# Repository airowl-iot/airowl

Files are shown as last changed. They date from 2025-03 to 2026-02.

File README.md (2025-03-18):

<div align="center">

# **AIROWL**

The Airowl is an indoor Air Quality Measurement device comprising of the ESP32 S3 powered M5stack Core S3 SE, which integrates the aforementioned controller chip, with a 320 x 240 LCD screen supporting capacitive touch, along with a speaker and the AXP2101 power management chip.



</div>

# Airowl is Now Matter-Compatible

Airowl now supports [**Matter**](https://en.wikipedia.org/wiki/Matter_(standard)), the new smart home standard, enabling seamless integration with **Apple HomeKit, Google Home**, and other Matter-supported ecosystems. Check the [Firmware](./Firmware) for details on Matter integration.

This repository serves as the source of the complete Airowl, consisting of its firmware source files, 3D files, and PCB design files.

This file provides instructions to assemble the individual components of the Airowl, along with its Bill of Materials (BOM).

## The BOM for the Airowl is as Follows:

| SR. | ITEM DESCRIPTION | NOTES | Qty | Product Links |
|-----|---|---|-----|---|
| 1 | M5 STACK | SCREEN | 1 | <a href="https://shop.m5stack.com/products/m5stack-cores3-se-iot-controller-w-o-battery-bottom" target="_blank">Link</a> |
| 2 | FRONT FACIA | UV FRONT 1.3 MM + REAR BLACK 5 MM | 1 | [Front](/Designfiles/Frontfacia) |
| 3 | 3D PRINT BACK CASE | BLACK MATTLE 3D PRINTED CASE | 1 | [Back](/Designfiles/Backcover) |
| 4 | FASTENERS | M3 X 8 mm PHILIPS HEAD (SS) | 2 | |
| 5 | FASTENERS | M3 X 20 mm CSK Blunted (SS) | 2 | |
| 6 | FASTENERS | M3 X 25 mm CSK Blunted (SS) | 2 | |
| 7 | Screw Driver (+) | Mini Screw Driver | 1 | |
| 8 | TYPE C - TYPE C CABLE | PORTRONICS TYPE C CABLE | 1 | |

More details of the individual components can be found as followed:

[PCB files](/Mountingboard/)

[Firmware](/Firmware)

[Squareline studio project files](/squareline/) 

[Design Files](/Designfiles/)

## Assembling the Airowl

The following is a cross sectional view of the Airowl dpicting its individual components and the way that they must be connected:

Design Files

From left to right, we can observe the parts as follows:

1. Screws
2. [3D printed Black Case](Images/16.png)
3. [Printed circuit Board](Images/19.png)
4. M5 stack Core S3 SE
5. Sensirion SEN 54 sensor
6. [Front Cover](Images/15.png)

Ensure that the screws are connected correctly as depicted in the above picture, incase the screws are connected incorrectly, the longer screws might damage the physical cover of the Airowl.

On assembling the Airowl, it appears like depicted below:



On following the instructions in [Firmware](/Firmware/), the Airowl can be programmed succesfully.

Check this repository releases for newer firmware updates.

## Made by the Community, with -❤️-:

<a href="https://github.com/oizom-iot/airowl/graphs/contributors">
  
</a>

## Licensing

Airowl is available under MIT License

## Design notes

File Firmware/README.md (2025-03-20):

# Firmware

This folder contains the firmware files used to program the Airowl. The Folder consists of various folders used by PlatformIO to configure and program the project.

## Using PlatformIO
PlatformIO is a VS code extension that enables us to program microcontrollers using VS code. The PlatformIO core supports more than 1500 development boards including the M5 core S3 used in the Airowl. PlatformIO supports both esp-idf and arduino environments. 

### Step 1  Installing PlatformIO 
PlatformIO can be installed using the extensions feature in Visual Studio Code.

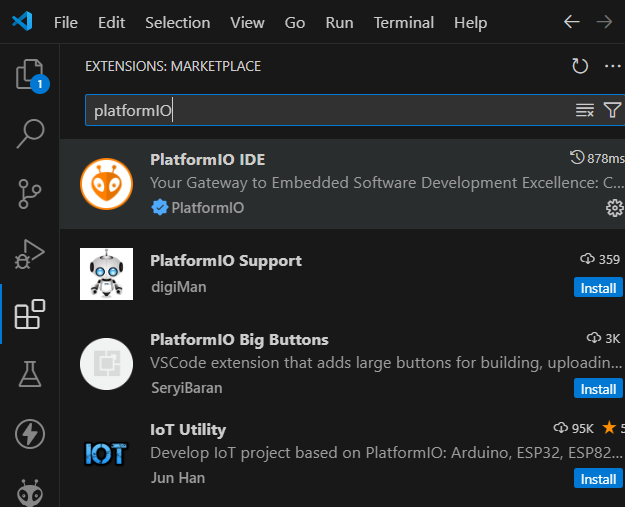
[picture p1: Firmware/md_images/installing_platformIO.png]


### Step 2 Using PlatformIO with Airowl Firmware

In order to program the Airowl with the firmware, download and extract this repository or clone it.
Open platformIO using the platformIO icon from the sidebar.

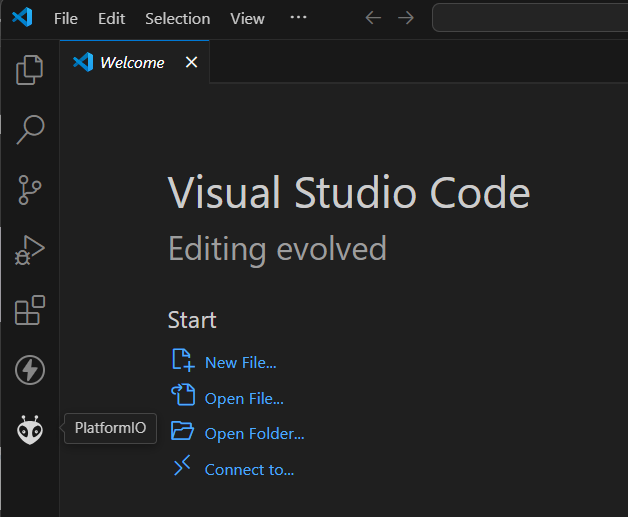
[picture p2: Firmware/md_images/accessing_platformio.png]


Open PIO home to access platformIO, this opens a new tab in VS code which can be used to create/open projects.

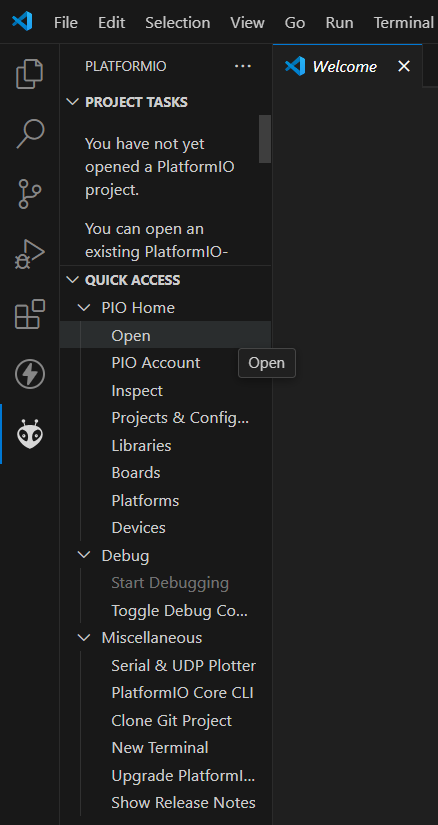
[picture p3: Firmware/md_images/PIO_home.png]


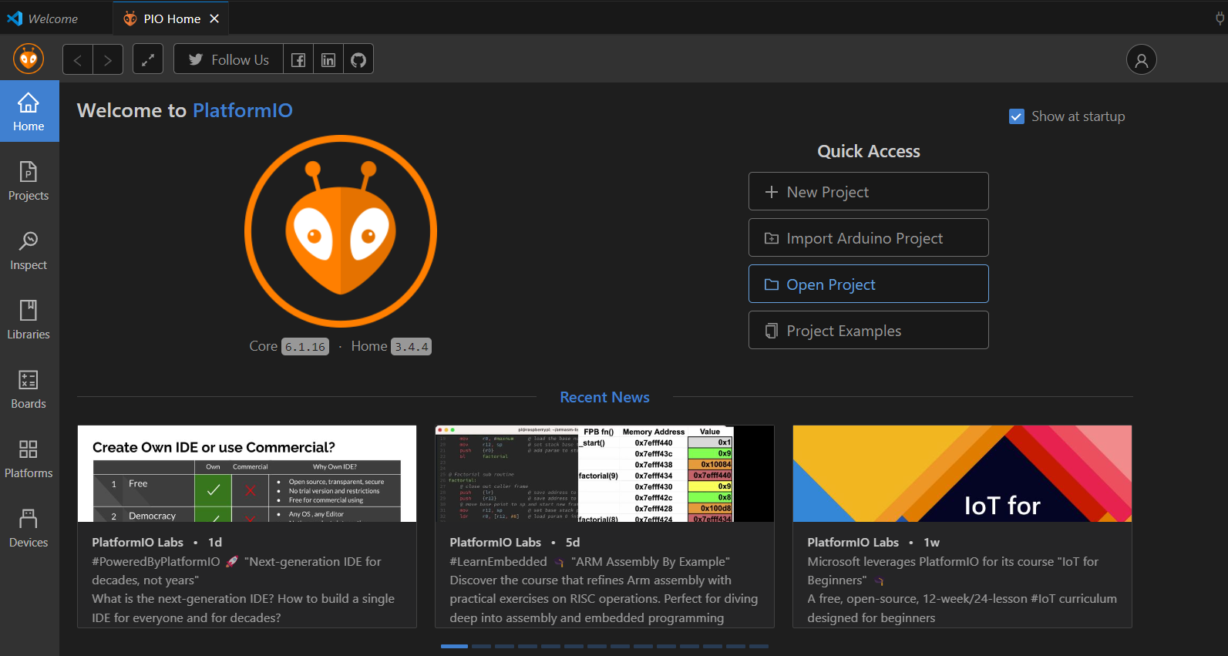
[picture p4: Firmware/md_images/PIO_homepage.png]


Click on Open Project button as highlighted in the above picture and locate the downloaded repository, and open the Firmware folder. Ensure that the folder has platformio.ini file present in it as this file acts as the config file for platformio and is essential to program the firmware to the Airowl. 

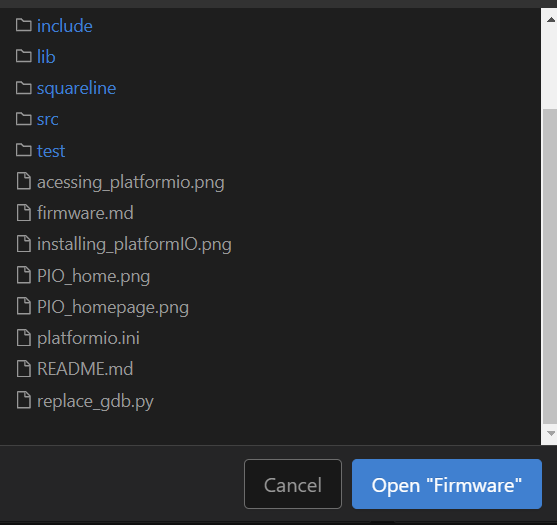
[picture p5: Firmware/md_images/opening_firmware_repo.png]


### Step 3  Uploading to the device using PlatformIO

Once the platformio.ini file is loaded, ensure that Airowl is connected to your PC, and upload the firmware using the PlatformIO : upload button



The terminal displays the upload status and on Successful upload displays the following :

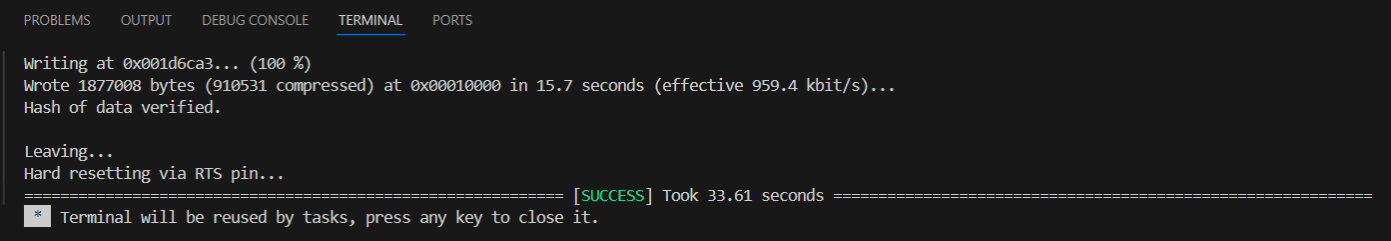
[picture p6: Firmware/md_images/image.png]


# Airowl Matter Device - Smart Home Integration

Airowl is a **Matter-compatible** device designed for seamless integration into various smart home ecosystems, including **Apple Home, Google Home, Amazon Alexa, Samsung SmartThings, Home Assistant and Other Supported Matter Ecosystem**. Unlike other devices that require a physical pairing button, Airowl **automatically enters pairing mode** after connecting to Wi-Fi using Wi-Fi Manager.

---

## 🔗 Supported Smart Home Ecosystems

Airowl can be added to the following **Matter-compatible** smart home platforms:

- **Apple Home**  
- **Google Home**  
- **Amazon Alexa**  
- **Samsung SmartThings**  
- **Home Assistant**
- **Other Supported Matter Ecosystem**
---

## 📲 Pairing Airowl with Apple Home

### Step 1: Power on the Airowl Device
- Connect the device to a **power source**.
- The device will create a **Wi-Fi hotspot** (e.g., **"Airowl-Setup"**).

### Step 2: Connect to Airowl’s Wi-Fi and Configure  
1. **Open Wi-Fi settings** on your phone and connect to **Airowl’s Wi-Fi** (SSID shown on the device).  
2. Once connected, a **Wi-Fi Manager portal** will open automatically. If not, go to **`192.168.4.1`** in a browser.  
3. Select your **home Wi-Fi network** and enter the password.  
4. Tap **Connect**, and Airowl will join your network.  

🚀 **At this point, the device automatically enters pairing mode!**  

### Step 3: Open Apple Home App  
1. Open the **Apple Home** app on your iPhone.  
2. Tap the **“+” (Add Accessory)** button in the top-right corner.  
3. Select **“Add Accessory.”**  

### Step 4: Scan the Matter QR Code

- Locate the **Matter QR Code** (on the device or in the documentation).
- Use your **iPhone camera** to scan the QR code.
- If there's no QR code, tap **“More Options”** and select the device from the list.

#### Matter QR Code:
Matter QR Code

#### Manual Pairing Code:
`34970112332`

### Step 5: Complete Setup  
- **Apple Home** will detect the Airowl device and guide you through the pairing process.  
- Assign it a **room** and a **custom name** (e.g., **"Living Room Air Sensor"**).  
- The device will now appear in **Apple Home**.  

---

## Squareline Studio

[Squareline Studio](https://squareline.io/) is a software that enables us to develop User Interface using LVGL, such that the tool converts visual design into LVGL based code allowing us to integrate images, logos, etc. in the project. 

[Squareline Studio Documentation](https://docs.squareline.io/docs/squareline/) 

Inside the firmware folder, the directory named [Squareline](/squareline/) stores the project files from squareline studio, these files contain the UI design.

### Step 1. Opening the Squareline Studio Project Files

[example_project.spj](/squareline/projects/ui_square_line/example_project.spj) is the squareline studio project file.

On launching Squareline Studio, click on the Import project button using which [example_project.spj](/squareline/projects/ui_square_line/example_project.spj) can be located and opened and modified accordingly.

On opening the project, we can see the various UI elements used to create the UI - such as the screens, images, buttons and the graphs created to portray the changing values of the parameters - measured using the SEN 54 sensor. 
Custom animations have been made for the Airowl with events created to trigger them.

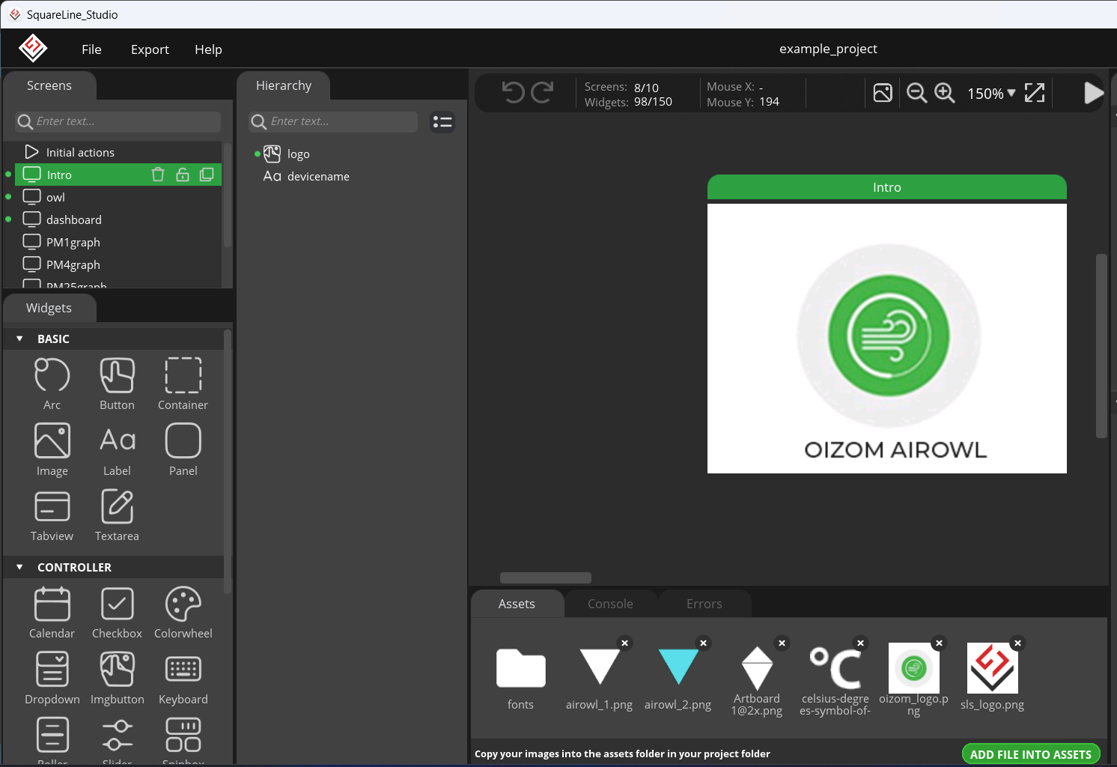
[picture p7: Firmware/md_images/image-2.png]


The screens panel on the side is jused to handle the screens, whereas  Widgets tab is used to add buttons/ containers/ labels etc.

The assets tab below the screens view is used to add images/ fonts to be used in the design.
Using the Add File into ASSETS option, more images can be added into the project.

On selecting the appropriate screen , the elements inside it are visible in the Heirarchy tab.

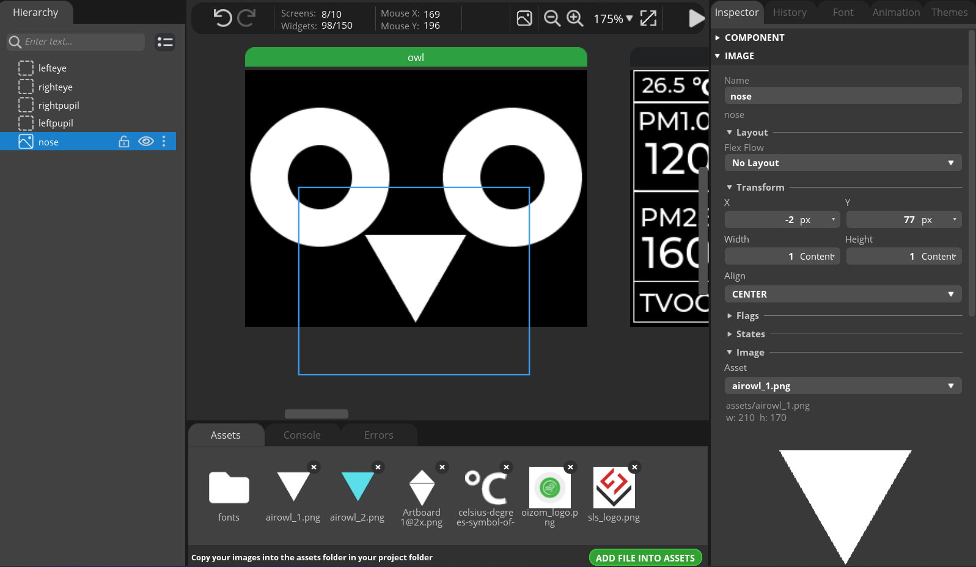
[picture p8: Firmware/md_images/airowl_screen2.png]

On selecting the element, we can modify the properties of the element through the inspector tab on the right such as size, position.
The font tab is used to handle the fonts used in the project.

The animation tab is usd to create/modify animations, the animations can be lated applied to different targets in the inspector tab.
The animations can be binded to events based on screen touch/ timeout basis from the inspector tab.

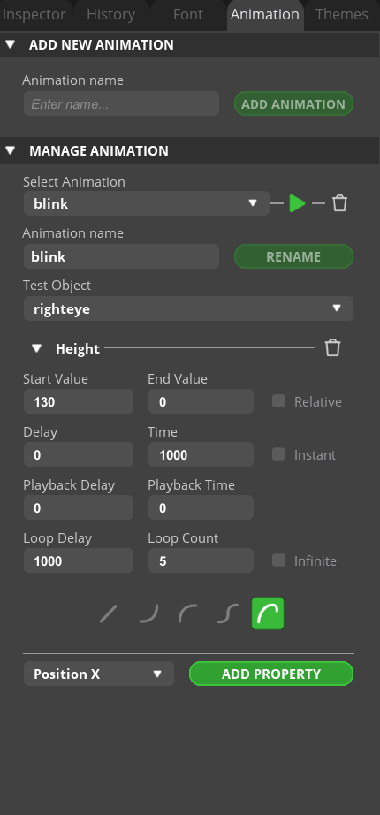
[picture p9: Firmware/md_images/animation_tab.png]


The white play button on the top (left of Inspector tab) can be clicked to simulate the animation, before using it in the Firmware.

### Step 2. Exporting the UI Files
Once the UI has been created , it is time to export the UI files. This can be done using the Export option on the top-left of the window. However, we must first ensure that the UI export path is correctly set inside the correct directory, this can be done using the file -> project settings option as depicted below:

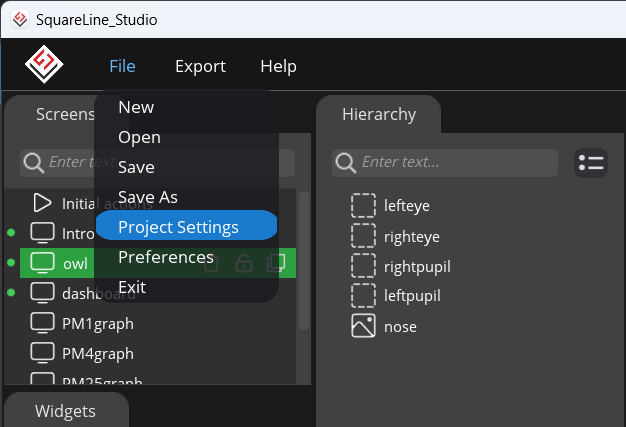
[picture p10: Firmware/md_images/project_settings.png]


It must be ensured that the Project export path is [ui_square_line](/squareline/projects/ui_square_line/) and the UI files export path is set to [/src/m5stack/ui/](/src/m5stack/ui/), this ensures that on updating the UI and exporting the UI files through Squareline Studio, the changes are reflected in the Firmware.

## src/m5stack

This folder contains the main files of the firmware. The C files, header files , UI files are all located inside this directory.

### ui
This folder contains the exported UI files from squareline studio (in source code format)

The fonts folder contains the custom fonts that we had added in the assets folder in squareline studio, the images folder contains the images used for the UI in C code, while the screens folder contains the C files for the various screens used in the UI design.
These files declare and use different objects to display the elements on the 320 x 240 LCD screen of the Airowl. Referencing these objects, and their types, we can manipulate them accordingly in order to update the UI based on sensor data and touch events.

The ui.c and ui.h files define all the animation functions, the labels, the conatiners and the objects that are used in the UI.These files also bind these objects to their repective LVGL components.

### main.cpp

Similar to Arduino IDE's .ino files, the main.cpp file consists of the setup() and loop() functions, this is actually the file executed by the platformIO core. It consists of inclusion of other header and UI files, which facilitates the usage of UI, and allows the functioning of I2C,Wifi,RTOS, MQTT functionality.
### Sensor.h 

The Sensor.h file acts as the backbone of the firmware. It defines and calls most functions required by the firmware.

To handle the SEN54 sensor, the file utilizes the appropriate library - <SensirionI2CSen5x.h>, this is the original arduino platform library, and handles the SEN 54 .

The Wire.h is the standard library used to handle I2C communication between the M5 Core S3's ESP32S3 microcontroller and the sensor. The M5 coreS3 and SEN 54 have interfaced as follows: 

1. SEN 54 VDD -> 5V 

2. SEN 54 GND -> GND

3. SEN 54 SCL -> G1

4. SEN 54 SDA -> G2

5. SEN 54 SEL -> GND    

Refer to the Pinmap of M5 core S3 SE below:

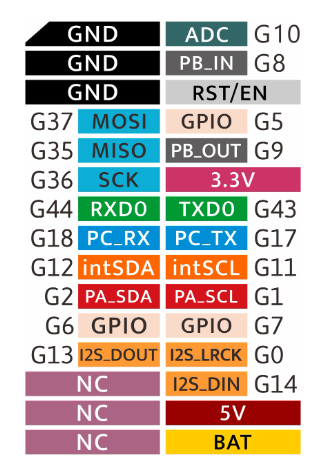
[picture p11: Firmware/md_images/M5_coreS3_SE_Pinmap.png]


Various LVGL UI objects are used in this file to overwrite/update the values displayed on the screen.
A data frequency of 150 has been defined which ensures that the graphs depicting PM1.0, PM 2.5, PM 4.0, PM 10.0 and TVOC are updated every 5 mins.

The live data is displayed on the dashboard screen, where the screen is divided into buttons, on touching the corresponding button, the graph of its parameter is displayed.

Functions - getAQIBreakpoint and getAQIColor are used to quantify the air quality index based on the PM and TVOC values, based on the AQI, the colors on the dashboard and the Owl screen are also updated.

Moreover Wifi.h and PubSubClient.h files are included to facilitate Wifi and MQTT functionalities respectively.

### time_func.h

This File handles the syncronization of the time label on the dashboard screen with the NTP server, using WifiManager functions.

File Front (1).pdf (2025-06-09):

## Step 3: Install the M5 Stack

## Congratulations !

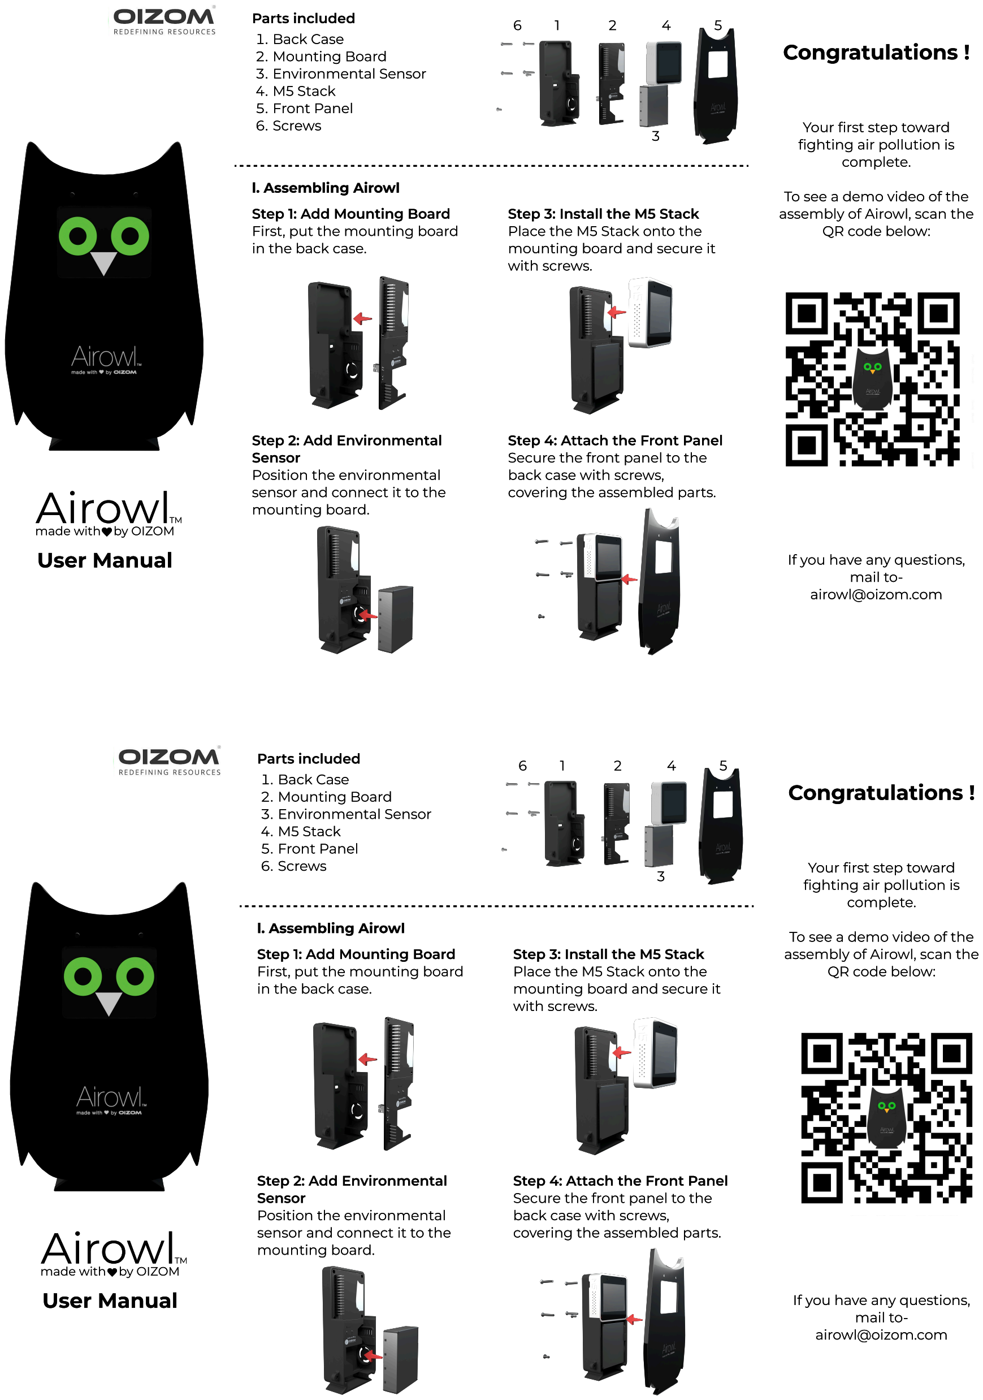
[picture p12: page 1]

## User Manual

### made with by OIZOM AirowlTM

Step 1: Add Mounting Board

First, put the mounting board

in the back case.

Place the M5 Stack onto the

mounting board and secure it

with screws.

Step 2: Add Environmental

Sensor

Position the environmental

sensor and connect it to the

mounting board.

### Step 4: Attach the Front Panel

Secure the front panel to the

back case with screws,

covering the assembled parts.

l. Assembling Airowl

Your first step toward

fighting air pollution is

complete.

To see a demo video of the

assembly of Airowl, scan the

QR code below:

If you have any questions,

## mail to-airowl@oizom.com

## Parts included

## +D Back Cas9

4D Mounting Boar(

/D Environmental Senso)

## AD M5 Stac2

:D Front Pane#

D Screws

6 | 1 | 2 | 4 | 5

3

## Parts included

## +D Back Cas9

4D Mounting Boar(

/D Environmental Senso)

## AD M5 Stac2

:D Front Pane#

D Screws

6 | 1 | 2 | 4 | 5

## Congratulations !

Your first step toward

fighting air pollution is

complete.

To see a demo video of the

assembly of Airowl, scan the

QR code below:

3

l. Assembling Airowl
Step 1: Add Mounting Board

First, put the mounting board

in the back case.

## Step 3: Install the M5 Stack

Place the M5 Stack onto the

mounting board and secure it

with screws.

Step 2: Add Environmental

Sensor

Position the environmental

sensor and connect it to the

mounting board.

### Step 4: Attach the Front Panel

Secure the front panel to the

back case with screws,

covering the assembled parts.

## User Manual

### made with by OIZOM AirowlTM

If you have any questions,

## mail to-airowl@oizom.com

## Parts included

## +D Back Cas9

4D Mounting Boar(

/D Environmental Senso)

## AD M5 Stac2

:D Front Pane#

D Screws

6 | 1 | 2 | 4 | 5

## Congratulations !

Your first step toward

fighting air pollution is

complete.

To see a demo video of the

assembly of Airowl, scan the

QR code below:

3

l. Assembling Airowl
Step 1: Add Mounting Board

First, put the mounting board

in the back case.

## Step 3: Install the M5 Stack

Place the M5 Stack onto the

mounting board and secure it

with screws.

Step 2: Add Environmental

Sensor

Position the environmental

sensor and connect it to the

mounting board.

### Step 4: Attach the Front Panel

Secure the front panel to the

back case with screws,

covering the assembled parts.

## User Manual

### made with by OIZOM AirowlTM

If you have any questions,

## mail to-airowl@oizom.com

## Parts included

## +D Back Cas9

4D Mounting Boar(

/D Environmental Senso)

## AD M5 Stac2

:D Front Pane#

D Screws

6 | 1 | 2 | 4 | 5

## Congratulations !

Your first step toward

fighting air pollution is

complete.

To see a demo video of the

assembly of Airowl, scan the

QR code below:

3

l. Assembling Airowl
Step 1: Add Mounting Board

First, put the mounting board

in the back case.

## Step 3: Install the M5 Stack

Place the M5 Stack onto the

mounting board and secure it

with screws.

Step 2: Add Environmental

Sensor

Position the environmental

sensor and connect it to the

mounting board.

### Step 4: Attach the Front Panel

Secure the front panel to the

back case with screws,

covering the assembled parts.

## User Manual

### made with by OIZOM AirowlTM

If you have any questions,

## mail to-airowl@oizom.com

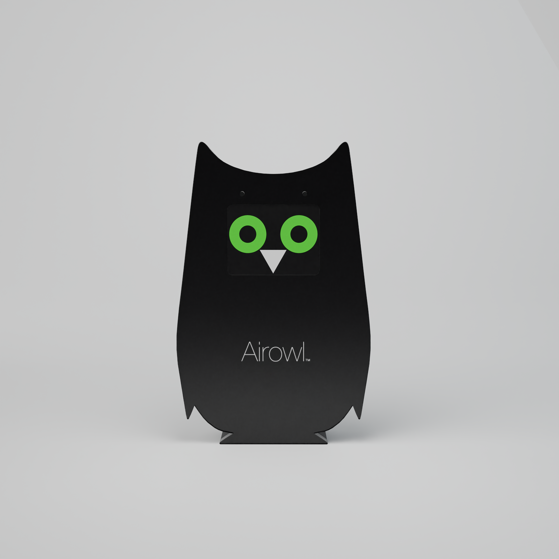
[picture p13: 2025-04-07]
Images/AIROWL edited renders and animation/n 2.png

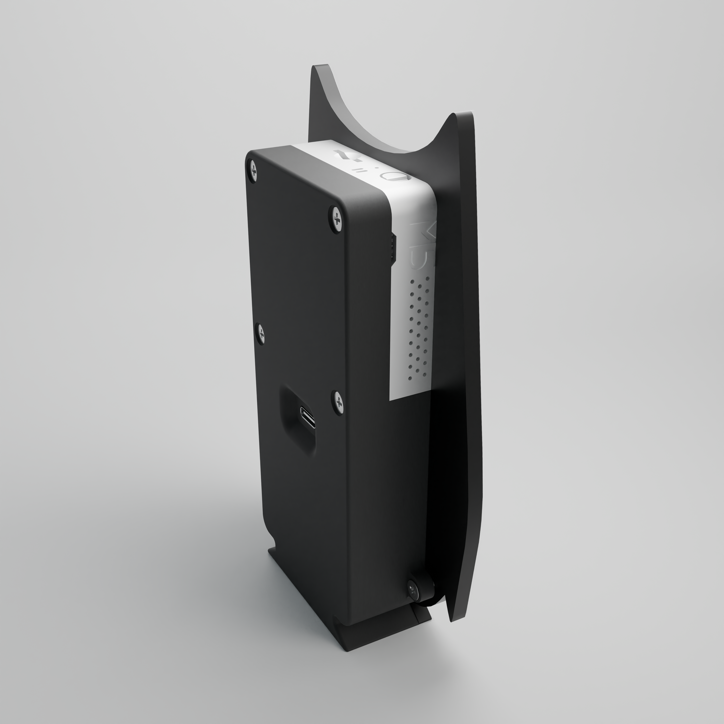
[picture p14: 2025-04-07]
Images/AIROWL edited renders and animation/n 3.png

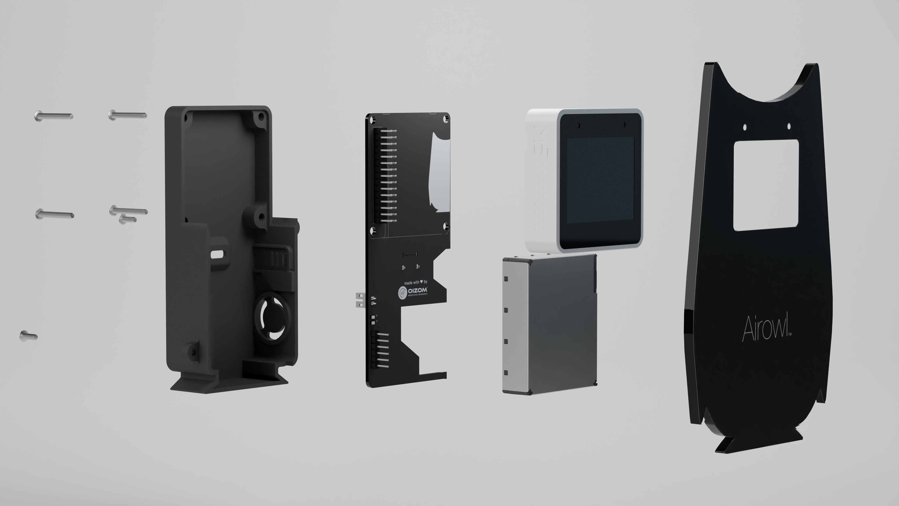
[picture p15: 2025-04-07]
Images/AIROWL edited renders and animation/n 6.png

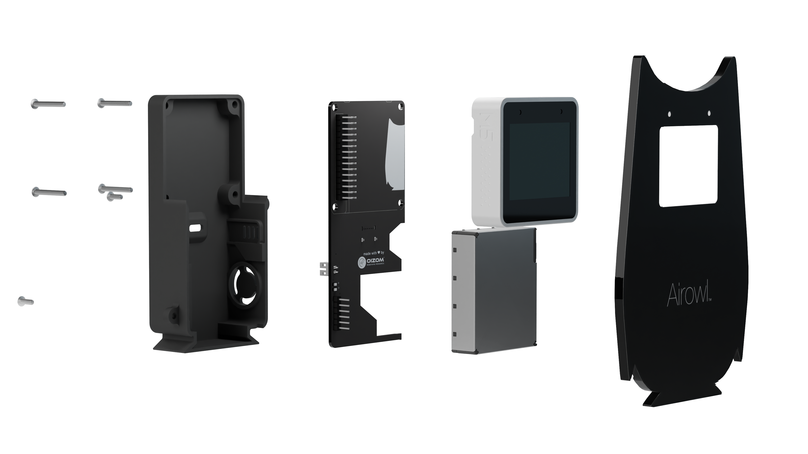
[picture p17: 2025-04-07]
Images/AIROWL edited renders and animation/n 6e.png

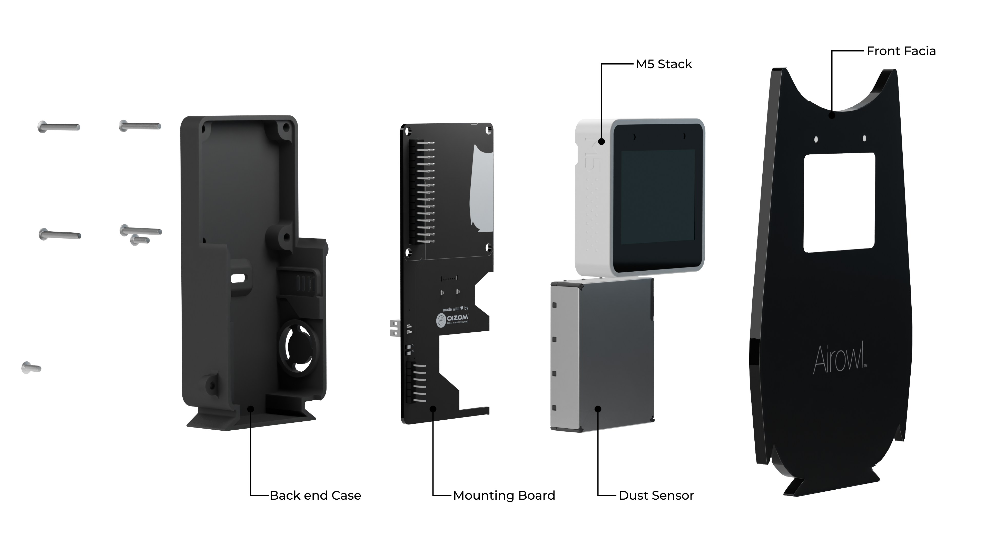
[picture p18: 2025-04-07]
Images/AIROWL edited renders and animation/n 6e2.png

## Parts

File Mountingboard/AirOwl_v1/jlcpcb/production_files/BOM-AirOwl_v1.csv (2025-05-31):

Comment | Designator | Footprint | LCSC
10K | R2 | R_0805_2012Metric_Pad1.20x1.40mm_HandSolder
10K | R1 | R_0805_2012Metric_Pad1.20x1.40mm_HandSolder
Conn_01x06 | J2 | PinHeader_1x06_P2.54mm_Vertical
USB_C_Receptacle_PowerOnly_6P | J4 | MOLEX_2171780001
SS34 | D2 | D_SMA
CoreSE | U1 | CoreS3
Conn_01x02 | J3 | JST_PH_B2B-PH-K_1x02_P2.00mm_Vertical
10K | R4 | R_0805_2012Metric_Pad1.20x1.40mm_HandSolder
10K | R3 | R_0805_2012Metric_Pad1.20x1.40mm_HandSolder

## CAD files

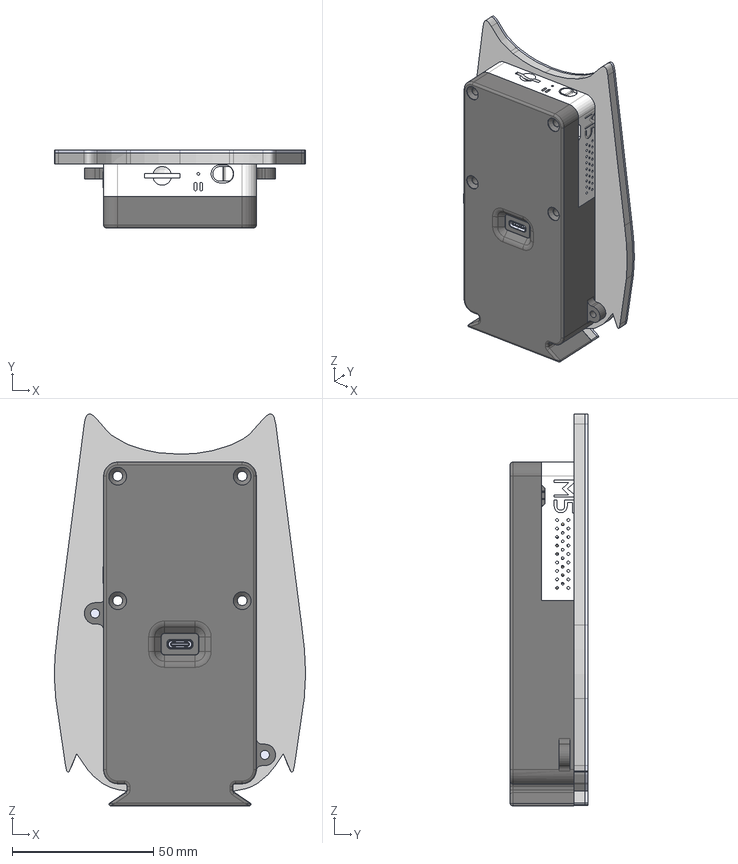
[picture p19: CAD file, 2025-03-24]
Designfiles/AirOwl Assembly.step
88.8 x 27.5 x 138.5 mm

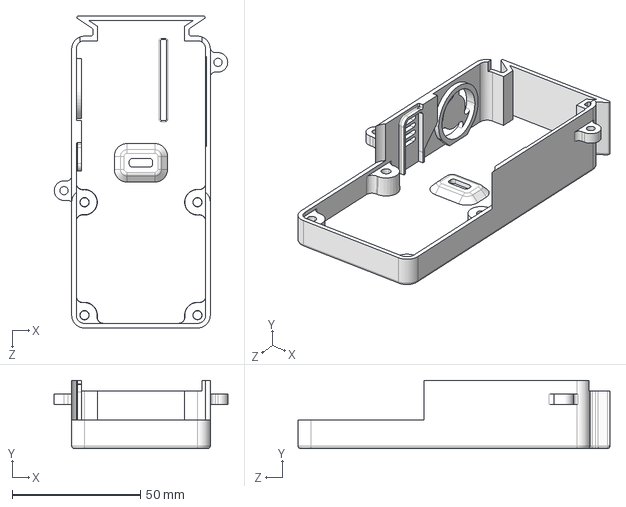
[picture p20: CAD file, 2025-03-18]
Designfiles/Backcover/Owl_2.0_component_case_V2.4.4.STEP
67.6 x 26.5 x 121.5 mm

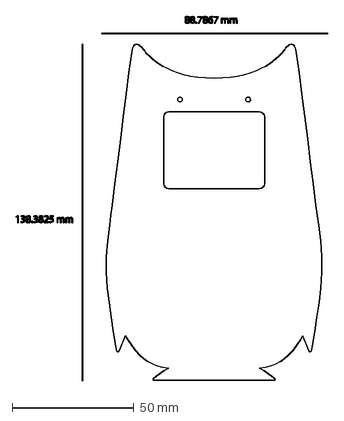
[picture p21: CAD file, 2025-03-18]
Designfiles/Frontfacia/Front facia 1mm.dxf
128.2 x 149.8 mm

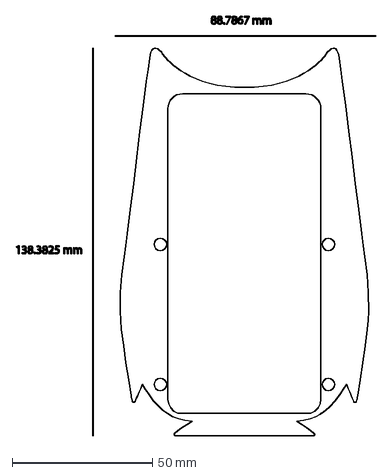
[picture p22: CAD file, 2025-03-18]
Designfiles/Frontfacia/Facia back plate 5mm (Black).dxf
128.2 x 149.8 mm

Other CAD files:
Designfiles/Backcover/Owl_2.0_component_case_V2.4.4.3MF

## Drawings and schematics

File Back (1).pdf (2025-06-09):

## Step 5: Configure Wi-Fi

## Included in the Kit¾

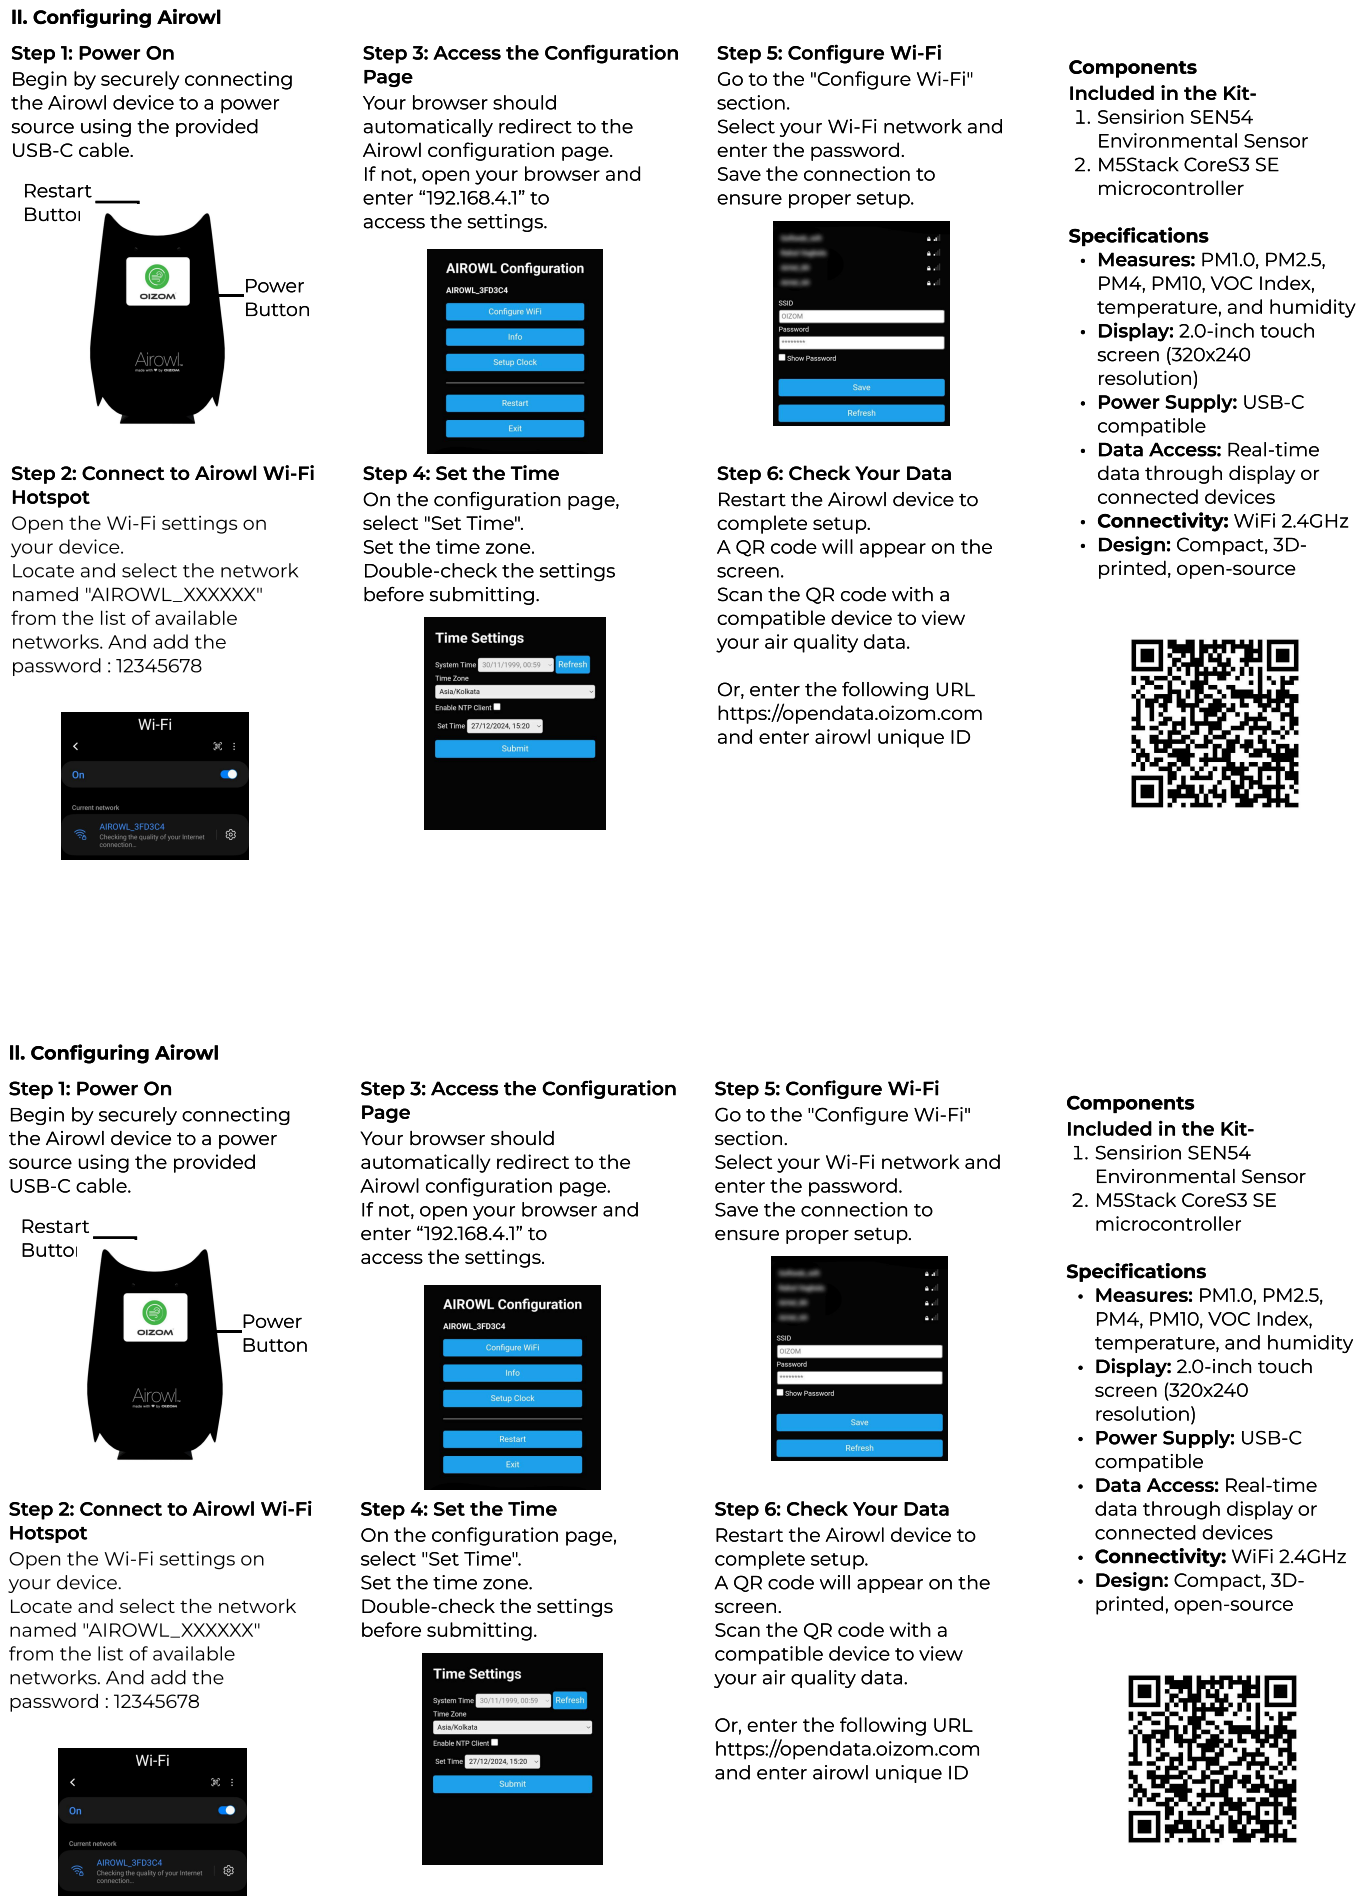
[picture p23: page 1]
USB-C cable.; section.; ½ Sensirion SEN54; Environmental SensoÀ; ½ M5Stack CoreS3 SE; microcontroller; Specificationz;  Measures: PM1.0, PM2.5,; PM4, PM10, VOC Index,; resolutiono; compatibl®; connected device¬;  Connectivity: WiFi 2.4GHa;  Design: Compact, 3D-; enter 192.168.4.1 to; Hotspot; your device.; complete setup.; before submitting.; Power; Button; Restart; Components

ll. Configuring Airowl

Step 1: Power On

Step 3: Access the Configuration
Page

Step 5: Configure Wi-Fi

Components
Included in the Kit¾

Begin by securely connecting

Go to the "Configure Wi-Fi"

the Airowl device to a power

Your browser should

source using the provided

automatically redirect to the

Select your Wi-Fi network and

Airowl configuration page.

enter the password.

If not, open your browser and

Save the connection to

ensure proper setup.

access the settings.

temperature, and humidit·

 Display: 2.0-inch touch
screen (320x240

 Power Supply: USB-C

 Data Access: Real-time
data through display or

Step 2: Connect to Airowl Wi-Fi

Step 4: Set the Time

Step 6: Check Your Data

On the configuration page,

Restart the Airowl device to

Open the Wi-Fi settings on

select "Set Time".

Set the time zone.

A QR code will appear on the

Locate and select the network
named "AIROWL_XXXXXX"
from the list of available

Double-check the settings

screen.
Scan the QR code with a

printed, open-source

compatible device to view

networks. And add the
password : 12345678

your air quality data.

Or, enter the following URL

https://opendata.oizom.com

and enter airowl unique ID

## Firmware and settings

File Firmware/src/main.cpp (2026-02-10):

#include <Arduino.h>
#include <esp_task_wdt.h>
#include <Wire.h>
#include "airowl_config.h"
#include "esp_system.h"
#include "esp_mac.h"
#include "manager/sensor_manager.h"
#include "manager/config_manager.h"
#include "manager/service_manager.h"
#include "manager/ui_manager.h"
#include <nvs_flash.h>

#define WDT_TIMEOUT_SECONDS 180


static void scanI2CBus(TwoWire &bus, const char *name, int sda, int scl)
{
  Serial.printf("\n[SCAN] %s (SDA=%d, SCL=%d)\n", name, sda, scl);
  int nDevices = 0;
  for (uint8_t address = 1; address < 127; ++address)
  {
    bus.beginTransmission(address);
    uint8_t error = bus.endTransmission();
    if (error == 0)
    {
      Serial.printf("  Found device at 0x%02X\n", address);
      ++nDevices;
    }
    else if (error == 4)
    {
      Serial.printf("  Unknown error at 0x%02X\n", address);
    }
    vTaskDelay(pdMS_TO_TICKS(5));
  }

  if (nDevices == 0) Serial.println("  No I2C devices found");
  else Serial.printf("  Done, found %d device(s)\n", nDevices);
}

// -------------------- Setup --------------------
void setup()
{
  Serial.begin(115200);
  delay(500);
  Serial.println("\n===== AIROWL BOOT =====");

  Serial.println("[BOOT] Initializing NVS flash...");
  esp_err_t ret = nvs_flash_init();
  if (ret == ESP_ERR_NVS_NO_FREE_PAGES || ret == ESP_ERR_NVS_NEW_VERSION_FOUND)
  {
    Serial.println("[BOOT] NVS partition needs to be erased, erasing...");
    ESP_ERROR_CHECK(nvs_flash_erase());
    ret = nvs_flash_init();
  }
  if (ret == ESP_OK) Serial.println("[BOOT] NVS initialized successfully");
  else Serial.printf("[BOOT] ERROR: NVS initialization failed with code: 0x%x\n", ret);

  esp_task_wdt_config_t wdt_config = {
      .timeout_ms = WDT_TIMEOUT_SECONDS * 1000,
      .idle_core_mask = (1 << portNUM_PROCESSORS) - 1,
      .trigger_panic = true};
  esp_task_wdt_reconfigure(&wdt_config);
  esp_task_wdt_add(NULL);

  Wire.begin(TOUCH_SDA, TOUCH_SCL);
  Wire.setClock(400000);

  Wire1.begin(CONFIG_SDA, CONFIG_SCL);
  Wire1.setClock(100000);

  vTaskDelay(pdMS_TO_TICKS(100));

  scanI2CBus(Wire, "I2C0 (Display/Touch)", TOUCH_SDA, TOUCH_SCL);
  scanI2CBus(Wire1, "I2C1 (Sensors)", CONFIG_SDA, CONFIG_SCL);

  if (!ConfigManager::getInstance()->initialize()) Serial.println("[BOOT] ConfigManager init failed!");
  else ConfigManager::getInstance()->printConfig();

  if (!APP::SensorManager::init()) Serial.println("[BOOT] SensorManager init failed!");
  else
  {
    APP::SensorManager::start();
    APP::SensorManager::startTask();
    Serial.println("[BOOT] SensorManager started");
  }

  if (!APP::UIController::init()) Serial.println("[BOOT] UIController init failed!");
  else
  {
    Serial.println("[BOOT] UIController initialized successfully");
    if (APP::UIController::startTask()) Serial.println("[BOOT] UIController task started");
    else Serial.println("[BOOT] Failed to start UIController task");
  }

  if (!APP::ServiceManager::getInstance().init()) Serial.println("[BOOT] ServiceManager init failed!");
  else
  {
    if (!APP::ServiceManager::getInstance().start()) Serial.println("[BOOT] Failed to start services!");
  }

}

void loop()
{
  esp_task_wdt_reset();
  vTaskDelay(pdMS_TO_TICKS(10));
}

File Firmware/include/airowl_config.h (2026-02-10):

#pragma once

#ifndef __CONFIG_H
#define __CONFIG_H


// TFT Display
#define TFT_WIDTH  240
#define TFT_HEIGHT 320
#define TFT_CS     39
#define TFT_DC     21
#define TFT_RST    47
#define TFT_SCLK   7
#define TFT_MOSI   6
#define TFT_BL     38

// Touch
#define TOUCH_SDA  4
#define TOUCH_SCL  5
#define TOUCH_RST  42
#define TOUCH_INT  41

#define PM700_SERIAL_BAUD 9600
#define PM700_RX_PIN 18

#define PMS_SERIAL_BAUD 9600
#define PMS_RX_PIN 44

#define CONFIG_SDA 10 
#define CONFIG_SCL 11 

#endif

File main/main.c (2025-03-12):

#include <stdio.h>
#include "freertos/FreeRTOS.h"
#include "freertos/task.h"
#include "nvs_flash.h"
#include "wifi_manager.h"
#include "ui_display.h"
#include "sensor_module.h"
#include "web_server.h"

void app_main(void)
{
    // Initialize NVS (required for WiFi)
    esp_err_t ret = nvs_flash_init();
    if (ret == ESP_ERR_NVS_NO_FREE_PAGES || ret == ESP_ERR_NVS_NEW_VERSION_FOUND) {
         nvs_flash_erase();
         nvs_flash_init();
    }

    // Start WiFi/hotspot manager (AP mode)
    wifi_manager_start();

    // Start web server for network configuration
    start_web_server();

    // Initialize UI/display and sensor modules
    ui_init();
    sensor_init();

    // Create tasks for UI update and sensor readings
    xTaskCreate(ui_task, "ui_task", 4096, NULL, 5, NULL);
    xTaskCreate(sensor_task, "sensor_task", 4096, NULL, 5, NULL);
}

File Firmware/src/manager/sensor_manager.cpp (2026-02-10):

#include "sensor_manager.h"
#include <esp_task_wdt.h>
#include "event_manager.h"
#include "../service/mqtt_service.h"
#include "../hal/hal_wifi.h"
#include "ui_manager.h"

namespace APP {

// -------- Static member definitions --------
bool SensorManager::initialized = false;
bool SensorManager::running = false;
TaskHandle_t SensorManager::sensorTaskHandle = nullptr;

float SensorManager::AQI = 0.0f;
float SensorManager::temperature = 0.0f;
float SensorManager::humidity = 0.0f;

SensorManager::SensorConfig SensorManager::pm700Config;
SensorManager::SensorConfig SensorManager::ahtConfig;

unsigned long SensorManager::lastPM700Read = 0;
unsigned long SensorManager::lastAHTRead = 0;
unsigned long SensorManager::lastPM700Publish = 0;
unsigned long SensorManager::lastAHTPublish = 0;

HAL::PM700::Data SensorManager::lastPM700Data;
HAL::AHT::Data SensorManager::lastAHTData;

bool SensorManager::newPM700Data = false;
bool SensorManager::newAHTData = false;

// Historical data buffers (2-hour history)
float SensorManager::pm25History[HISTORY_BUFFER_SIZE] = {0};
float SensorManager::pm10History[HISTORY_BUFFER_SIZE] = {0};
float SensorManager::tempHistory[HISTORY_BUFFER_SIZE] = {0};
float SensorManager::humdHistory[HISTORY_BUFFER_SIZE] = {0};
float SensorManager::tvocHistory[HISTORY_BUFFER_SIZE] = {0};
float SensorManager::eco2History[HISTORY_BUFFER_SIZE] = {0};

int SensorManager::historyIndex = 0;
int SensorManager::historyCount = 0;

// Temporary buffers for 2-minute averaging
float SensorManager::pm25TempBuffer[TEMP_BUFFER_SIZE] = {0};
float SensorManager::pm10TempBuffer[TEMP_BUFFER_SIZE] = {0};
float SensorManager::tempTempBuffer[TEMP_BUFFER_SIZE] = {0};
float SensorManager::humdTempBuffer[TEMP_BUFFER_SIZE] = {0};
float SensorManager::tvocTempBuffer[TEMP_BUFFER_SIZE] = {0};
float SensorManager::eco2TempBuffer[TEMP_BUFFER_SIZE] = {0};

int SensorManager::pmTempIndex = 0;
int SensorManager::pmTempCount = 0;
int SensorManager::ahtTempIndex = 0;
int SensorManager::ahtTempCount = 0;

unsigned long SensorManager::lastMqttPublish = 0;

// -------- Lifecycle --------
bool SensorManager::init() {
    if (initialized) return true;

    auto* cfg = ConfigManager::getInstance();
    if (!cfg || !cfg->isInitialized()) {
        Serial.println("[SensorManager] ConfigManager not ready");
        return false;
    }

    if (!loadConfigsFromManager()) return false;

    bool any = false;
    if (pm700Config.enabled) any |= HAL::PM700::init();
    if (ahtConfig.enabled) any |= HAL::AHT::init();

    initialized = any;
    return initialized;
}

bool SensorManager::init(const SensorConfig& pm700Cfg,
                         const SensorConfig& ahtCfg) {
    if (initialized) return true;
    pm700Config = pm700Cfg;
    ahtConfig = ahtCfg;
   

    initialized = (pm700Cfg.enabled && HAL::PM700::init()) ||
                  (ahtCfg.enabled && HAL::AHT::init()) ;
    return initialized;
}

bool SensorManager::start() {
    if (!initialized) return false;
    running = true;
    return true;
}

void SensorManager::stop() { running = false; }
bool SensorManager::isRunning() { return running; }

// -------- Config handling --------
void SensorManager::updateConfigFromManager() {
    auto* cfg = ConfigManager::getInstance();
    if (!cfg || !cfg->isInitialized()) return;
    loadConfigsFromManager();
}

void SensorManager::updateConfig(const SensorConfig& pm700Cfg,
                                 const SensorConfig& ahtCfg) {
    pm700Config = pm700Cfg;
    ahtConfig = ahtCfg;
}

const SensorManager::SensorConfig& SensorManager::getPM700Config() { return pm700Config; }
const SensorManager::SensorConfig& SensorManager::getAHTConfig() { return ahtConfig; }

// -------- Sensor read handlers --------

void SensorManager::readPM700Sensor() {
    if (!pm700Config.enabled || !running) return;
    auto now = millis();
    if (now - lastPM700Read < pm700Config.readInterval) return;

    lastPM700Read = now;
    HAL::PM700::Error result = HAL::PM700::read(&lastPM700Data);
    if (result == HAL::PM700::Error::NONE &&
        HAL::PM700::isDataAvailable()) {
        newPM700Data = true;
        float vals[] = { lastPM700Data.pm25, lastPM700Data.pm10,
                         lastPM700Data.p03, lastPM700Data.pm1 };

        // Store in temporary buffer for 2-minute averaging
        pm25TempBuffer[pmTempIndex] = lastPM700Data.pm25;
        pm10TempBuffer[pmTempIndex] = lastPM700Data.pm10;
        pmTempIndex = (pmTempIndex + 1) % TEMP_BUFFER_SIZE;
        if (pmTempCount < TEMP_BUFFER_SIZE) {
            pmTempCount++;
        }

        auto event = std::make_shared<CORE::SensorReadingEvent>(
            CORE::SensorReadingEvent::SensorType::PM700,
            0,  // sensorId
            vals,
            4
        );
        CORE::EventBus::getInstance().publish(event);
        // Serial.printf("[SensorManager] Published PM700 data: PM2.5=%.1f, PM10=%.1f\n",
        //               lastPM700Data.pm25, lastPM700Data.pm10);
    } else if (result != HAL::PM700::Error::NONE) {
        vTaskDelay(pdMS_TO_TICKS(500));
    }
}

void SensorManager::readAHTSensor() {
    if (!ahtConfig.enabled || !running) return;
    auto now = millis();
    if (now - lastAHTRead < ahtConfig.readInterval) return;

    lastAHTRead = now;
    HAL::AHT::Error result = HAL::AHT::read(&lastAHTData);
    if (result == HAL::AHT::Error::NONE &&
        HAL::AHT::isDataAvailable()) {
        newAHTData = true;
        
        float vals[] = { lastAHTData.temperature, lastAHTData.humidity,
                        (float)lastAHTData.tvoc, (float)lastAHTData.eco2 };

        // Store in temporary buffer for 2-minute averaging
        tempTempBuffer[ahtTempIndex] = lastAHTData.temperature;
        humdTempBuffer[ahtTempIndex] = lastAHTData.humidity;
        tvocTempBuffer[ahtTempIndex] = (float)lastAHTData.tvoc;
        eco2TempBuffer[ahtTempIndex] = (float)lastAHTData.eco2;
        ahtTempIndex = (ahtTempIndex + 1) % TEMP_BUFFER_SIZE;
        if (ahtTempCount < TEMP_BUFFER_SIZE) {
            ahtTempCount++;
        }

        temperature = lastAHTData.temperature;
        humidity = lastAHTData.humidity;
        AQI = (float)lastAHTData.aqi;

        auto event = std::make_shared<CORE::SensorReadingEvent>(
            CORE::SensorReadingEvent::SensorType::AHT,
            0,  // sensorId
            vals,
            4
        );
        CORE::EventBus::getInstance().publish(event);
        // Serial.printf("[SensorManager] Published AHT data: Temp=%.1f°C, Humidity=%.1f%%\n",
        //               lastAHTData.temperature, lastAHTData.humidity);
    } else if (result != HAL::AHT::Error::NONE) {
        vTaskDelay(pdMS_TO_TICKS(500));
    }
}
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

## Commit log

2025-03-12 tesing in esp-idf
    [AirOwl_v1-CuBottom.gbr, AirOwl_v1-CuTop.gbr, AirOwl_v1-EdgeCuts.gbr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]
2025-03-18 Wifi MacAddress bug resolved
    [main.cpp]
2025-03-24 Create AirOwl Assembly.step
    [AirOwl Assembly.step]
2025-06-09 MANUAL ADDED
    [Owl_2.0_component_case_V2.4.4.3MF]
2025-07-03 matter code included
    [partitions.csv]
2025-07-18 Flags feature integration with all working modules
    [partitions.csv]
2025-07-27 Updated LED Breathing Logic
2025-07-27 Updated Sensor logic
2025-09-03 Updated sensor implementation
2025-09-19 config based architecture
    [partitions.csv]
